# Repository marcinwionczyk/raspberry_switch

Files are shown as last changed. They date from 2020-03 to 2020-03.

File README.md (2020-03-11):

# raspberry_switch
A switch to turn on and truly turn off raspberry Pi (Zero).

## How it works

From schematic point of view, it look like this:

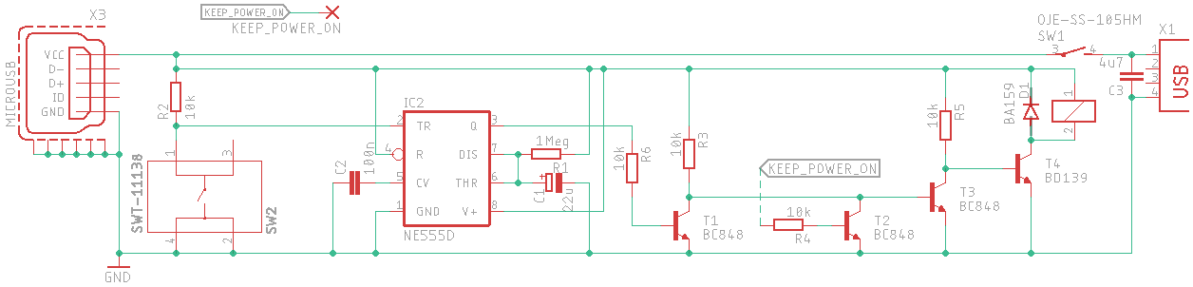
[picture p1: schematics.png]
Schematics


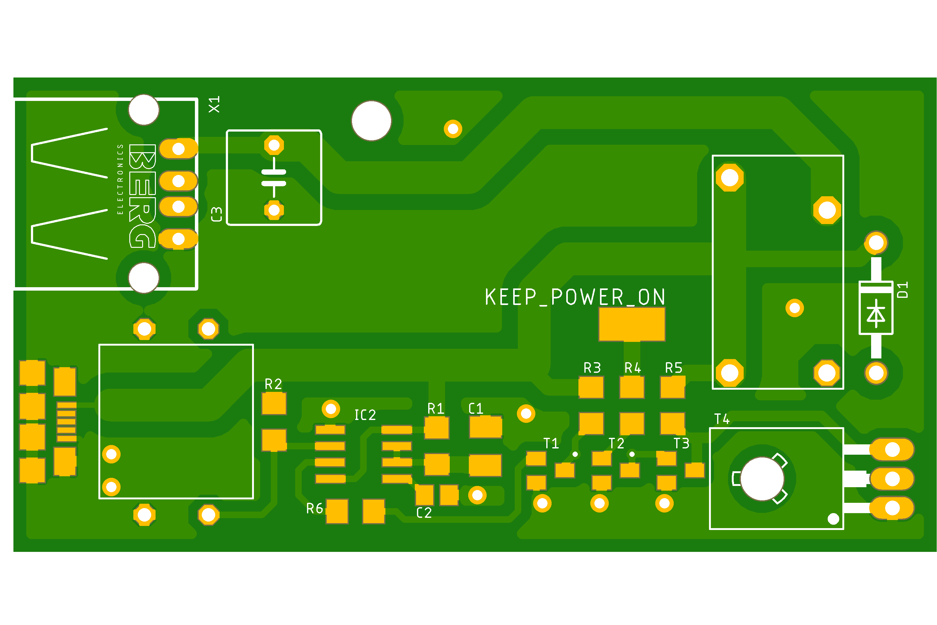
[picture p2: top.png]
Top view


When SW2 switch is pressed, NE555 will keep power on for approximately 24 seconds.
During this time, Raspberry Pi will boot and start service 
[relay_switch_on](software/lib/systemd/system/relay_switch_on.service) which set pin GPIO12 as output with high state.
 
When Pi is halted, service [relay_switch_off](software/lib/systemd/system/relay_switch_off.service) will set GPIO12 to 
low and effectively cut off the power. 

## Hardware
I have designed PCB with Autodesk Eagle. You may download and change according to your liking: 
* [schematics](hardware/Autodesk%20Eagle%20project/main.sch), 
* [board](hardware/Autodesk%20Eagle%20project/main.brd)

There are also [gerber files](hardware/gerber_files.zip)

## How to install
1. Copy everything from software folder into your root folder
1. Make python scripts executable:
    1. `sudo chmod +x /usr/local/bin/relayOff.py` 
    1. `sudo chmod +x /usr/local/bin/relayOn.py`
1. Execute below commands:
    1. `systemctl daemon-reload`
    1. `systemctl enable relay_switch_on`
    1. `systemctl enable relay_switch_off`
1. Connect pin GPIO12 with wire to signal "KEEP_POWER_ON".
1. Power off
1. Plug usb output from power adapter into X3 connector
1. Connect with usb cable X1 connector and raspberry pi input power

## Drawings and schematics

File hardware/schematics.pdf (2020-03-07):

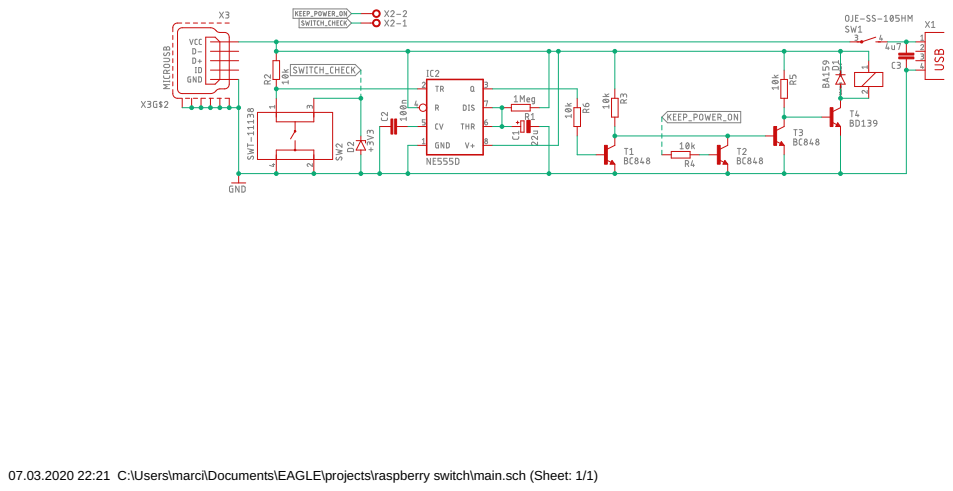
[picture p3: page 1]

07.03.2020 22:21 C:\Users\marci\Documents\EAGLE\projects\raspberry switch\main.sch (Sheet: 1/1)

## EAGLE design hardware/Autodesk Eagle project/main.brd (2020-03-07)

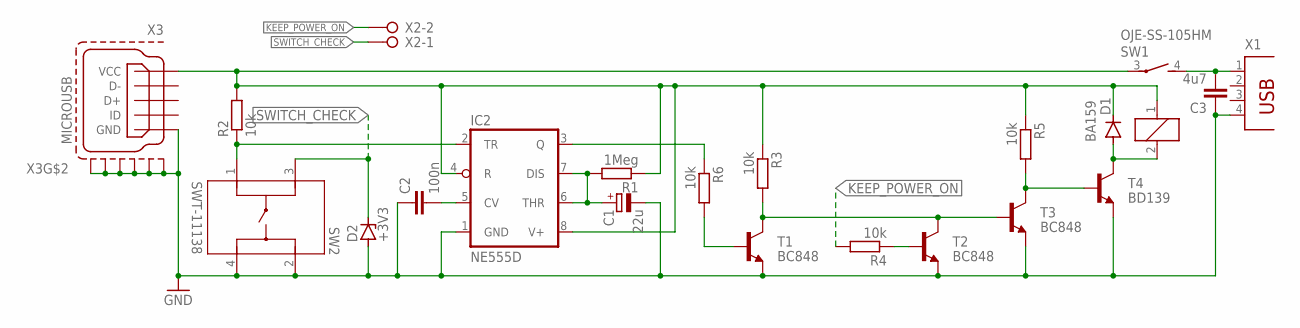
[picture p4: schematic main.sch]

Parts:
C1: 22u; SMC_B
C2: 100n; C0805
C3: 4u7; C050-075X075
D1: BA159; DO41-10
D2: +3V3; SOD80C
IC2: NE555D; SO08
R1: 1Meg; R1206
R2, R3, R4, R5, R6: 10k; R1206
SW1: OJE-SS-105HM
SW2: SWT-11138
T1, T2, T3: BC848; SOT23
T4: BD139; TO126
X1: PN87520
X2: W237-02P; W237-132
X3: MICROUSB

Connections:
+5V: D1.C, IC2.4 (R), IC2.8 (V+), R1.1, R2.2, R3.1, R5.1, SW1.1, SW1.3, X3.1 (VCC)
GND: C1.-, C2.1, C3.1, D2.A, IC2.1 (GND), SW2.2 (4), SW2.4 (3), T1.2 (E), T2.2 (E), T3.2 (E), T4.1 (E), X1.4, X3.5 (GND), X3.P$1 (S1), X3.P$2 (S2), X3.P$3 (S3), X3.P$4 (S4), X3.P$5 (S5), X3.P$6 (S6)
KEEP_POWER_ON: R4.2, X2.2
unnamed: C1.+, IC2.6 (THR), IC2.7 (DIS), R1.2
unnamed: R6.2, T1.1 (B)
unnamed: C2.2, IC2.5 (CV)
unnamed: IC2.2 (TR), R2.1, SW2.1
unnamed: IC2.3 (Q), R6.1
unnamed: R5.2, T3.3 (C), T4.3 (B)
unnamed: C3.2, SW1.4 (S), X1.1
unnamed: R4.1, T2.1 (B)
unnamed: R3.2, T1.3 (C), T2.3 (C), T3.1 (B)
unnamed: D1.A, SW1.2, T4.2 (C)
SWITCH_CHECK: D2.C, SW2.3 (2), X2.1

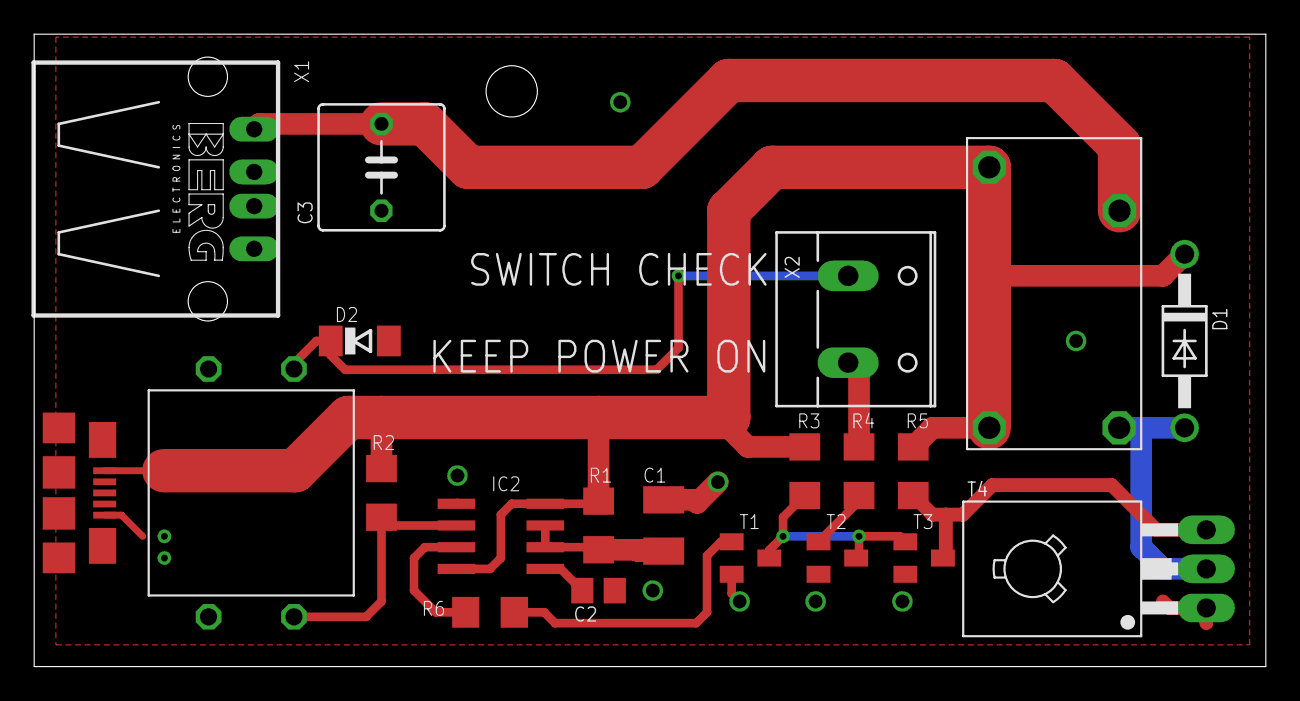
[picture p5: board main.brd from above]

Board: 2 copper layers, 72.1 x 37.0 mm, 21 parts (0 on the bottom side), 14 nets.

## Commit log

2020-03-11 Removed "SWITCH_CHECK" signal. Does not work as expected. Somehow it turns on Raspberry Pi.
    Added gerber files
2020-03-11 removed sensing input on GPIO6 pin
